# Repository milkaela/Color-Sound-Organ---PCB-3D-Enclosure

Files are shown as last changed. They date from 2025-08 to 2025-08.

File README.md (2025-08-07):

# Color Sound Organ: PCB-3D-Enclosure
This project contains a complete design for a **sound-reactive light organ** with 3 channels (bass, mid, treble), using a PCB designed in KiCad and a custom 3D-printed case modeled in FreeCAD.
It is intended as a simple analog project for beginners or hobbyists who want to create visual effects based on audio input.

## 📦 Files Included

| File | Description |
|---|---|
| `3leduri.kicad_pcb` | PCB layout for the sound organ |
| `3leduri.kicad_sch` | Schematic diagram (circuit design) |
| `3leduri.kicad_pro` | KiCad project file |
| `3leduri.kicad_prl` | Layout view settings |
| `3leduri.xml` | Netlist and BOM data export |
| `3leduri_bom_.csv`  | Bill of materials (CSV format) |
| `3leduri_bom_.xlsx` | Bill of materials (Excel format) |
| `fp-info-cache` | Footprint cache used by KiCad |
| `cutie2.1.FCStd` | 3D model of the custom case (FreeCAD format) |
---

## 🧠 Functional Description

The circuit detects three different frequency bands from an audio signal (low, mid, and high), and lights up a dedicated LED for each band accordingly.

- **Low frequencies (bass)** → LED 1
- **Mid frequencies** → LED 2
- **High frequencies (treble)** → LED 3

The PCB is designed to fit perfectly into the custom enclosure, with holes for LEDs and power input.

---

## 🛠 Tools and Technologies

- **KiCad** – for PCB design
- **FreeCAD** – for designing the case
- **3D Printer** – to fabricate the enclosure
- (Optional) **Audio signal source** – via jack, aux, or microphone

---

## 🖨️ 3D Printing Information

- Format: `.FCStd` (native FreeCAD file)
- Recommended slicer: Cura, PrusaSlicer, etc.
- Material: PLA or PETG
- Print time: ~2 hours
- No supports required

---

## ⚡ Usage & Testing

1. Assemble the circuit and solder components on the PCB
2. Insert the board into the 3D-printed case
3. Connect audio input (e.g. from your phone or laptop)
4. Play music — the 3 LEDs will respond to the audio spectrum

---

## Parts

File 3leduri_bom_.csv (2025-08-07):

Component | Description | Part | References | Value | Footprint | Quantity Per PCB | Datasheet | mfr.part.no | sup.ref | Sim.Pins
1 | Unpolarized capacitor | C | C9 | 4.7n | C_1206_3216Metric_Pad1.33x1.80mm_HandSolder | 1 | ~ | GRM31CR72E473KW03L | https://ro.mouser.com/ProductDetail/Murata-Electronics/GRM31CR72E473KW03L?qs=NdShG4hwR%2FfxjPAa9M%2FghA%3D%3D
2 | Unpolarized capacitor | C | C6 C7 | 22n | C_1206_3216Metric_Pad1.33x1.80mm_HandSolder | 2 | ~ | GRM31BR72E223KW01L | http://ro.mouser.com/ProductDetail/Murata-Electronics/GRM31BR72E223KW01L?qs=ra6ln1utXjhhO7tH%2Fqm%252BxQ%3D%3D
3 | Unpolarized capacitor | C | C3 | 0.22u | C_1206_3216Metric_Pad1.33x1.80mm_HandSolder | 1 | ~ | GRM31C5C1H224JE02L | https://ro.mouser.com/ProductDetail/Murata-Electronics/GRM31C5C1H224JE02L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
4 | Unpolarized capacitor | C | C4 | 1u | C_1206_3216Metric_Pad1.33x1.80mm_HandSolder | 1 | ~ | GCM31CR71H105KA55L | https://ro.mouser.com/ProductDetail/Murata-Electronics/GCM31CR71H105KA55L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
5 | Unpolarized capacitor | C | C5 C8 C10 | 4.7u | C_1206_3216Metric_Pad1.33x1.80mm_HandSolder | 3 | ~ | GCM31CC71H475MA03K | https://ro.mouser.com/ProductDetail/Murata-Electronics/GCM31CC71H475MA03K?qs=QzBtWTOodeVm6tBb%2FlTxEw%3D%3D
6 | Unpolarized capacitor | C | C2 | 10u | C_1206_3216Metric_Pad1.33x1.80mm_HandSolder | 1 | ~ | GRM31MR61A106KE19L | https://ro.mouser.com/ProductDetail/Murata-Electronics/GRM31MR61A106KE19L?qs=uLxxDnpYPrNhLv76oVsT4Q%3D%3D
7 | Unpolarized capacitor | C | C1 | 47u | C_1206_3216Metric_Pad1.33x1.80mm_HandSolder | 1 | ~ | GCJ31CD70G476ME01L | https://ro.mouser.com/ProductDetail/Murata-Electronics/GCJ31CD70G476ME01L
8 | Light emitting diode | LED | D1 D2 D3 D4 D5 D6 D7 D8 D9 D10 D11 D12 D13 D14 D15 D16 D17 D18 | LED | LED_D5.0mm | 18 | ~ | MTE1201C1 | https://ro.mouser.com/ProductDetail/Marktech-Optoelectronics/MTE1201C1 | 1=K 2=A
9 | Generic screw terminal, single row, 01x02, script generated (kicad-library-utils/schlib/autogen/connector/) | Screw_Terminal_01x02 | J1 J3 | Screw_Terminal_01x02 | TerminalBlock_Phoenix_MKDS-1,5-2_1x02_P5.00mm_Horizontal | 2 | ~ | 1732386 | https://ro.mouser.com/ProductDetail/Phoenix-Contact/1732386?qs=q88POAGIlTFn%2F3dpEE3JiQ%3D%3D
10 | 0.5A Ic, 300V Vce, NPN High Voltage Transistor, TO-92 | MPSA42 | Q1 Q2 Q3 Q4 Q5 Q6 Q7 Q8 | MPSA42 | TO-92_Inline | 8 | http://www.onsemi.com/pub_link/Collateral/MPSA42-D.PDF | MPSA42 | https://ro.mouser.com/ProductDetail/onsemi-Fairchild/MPSA42?qs=UMEuL5FsraDu%2F9ZWGlN1JQ%3D%3D
11 | Resistor | R | R5 | 1.2m | R_1206_3216Metric_Pad1.30x1.75mm_HandSolder | 1 | ~ | AC1206JR-071M2L | https://ro.mouser.com/ProductDetail/YAGEO/SR1206JR-1347RL?qs=xt%2FK%252BZwdrcX9lgw8VMC4Xg%3D%3D
12 | Resistor | R | R4 R17 R20 | 47r | R_1206_3216Metric_Pad1.30x1.75mm_HandSolder | 3 | ~ | SR1206JR-1347RL | https://ro.mouser.com/ProductDetail/TE-Connectivity-Neohm/EP4WSS47RJ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
13 | Resistor | R | R10 R15 R16 R16b1 R21 R21b1 | 150r | R_1206_3216Metric_Pad1.30x1.75mm_HandSolder | 6 | ~ | SR1206JR-7W150RL | https://ro.mouser.com/ProductDetail/YAGEO/SR1206JR-7W150RL?qs=1X5yxNMcnLxagzLVGX4DGA%3D%3D
14 | Resistor | R | R11 R11b1 | 270r | R_1206_3216Metric_Pad1.30x1.75mm_HandSolder | 2 | ~ | RCA1206270RJNEA | https://ro.mouser.com/ProductDetail/Vishay/RCA1206270RJNEA?qs=VVKQmw408U%2FD9LNLQdRT1g%3D%3D
15 | Resistor | R | R6 | 470r | R_1206_3216Metric_Pad1.30x1.75mm_HandSolder | 1 | ~ | SR1206KR-7W470RL | https://ro.mouser.com/ProductDetail/YAGEO/SR1206KR-7W470RL?qs=ABvmyp11Kkjj9l8C%2F3PCeg%3D%3D
16 | Resistor | R | R1 R2 | 1k | R_1206_3216Metric_Pad1.30x1.75mm_HandSolder | 2 | ~ | RV1206JR-071KL | https://ro.mouser.com/ProductDetail/YAGEO/RV1206JR-071KL?qs=HEu%2FF%2FCqxzLBGGLzy5MRbA%3D%3D
17 | Resistor | R | R7 R12 | 4.7k | R_1206_3216Metric_Pad1.30x1.75mm_HandSolder | 2 | ~ | AR1206JR-074K7L | https://ro.mouser.com/ProductDetail/YAGEO/AR1206JR-074K7L?qs=r5DSvlrkXmLp85SEw6xssw%3D%3D
18 | Resistor | R | R3 R9 R14 R19 | 10k | R_1206_3216Metric_Pad1.30x1.75mm_HandSolder | 4 | ~ | ERJ-U08J103V | https://ro.mouser.com/ProductDetail/Panasonic/ERJ-U08J103V?qs=pdFhdcvjjghFvwXjR90D9A%3D%3D
19 | Resistor | R | R8 R13 R18 | 270k | R_1206_3216Metric_Pad1.30x1.75mm_HandSolder | 3 | ~ | AF1206JR-07270KL | https://ro.mouser.com/ProductDetail/YAGEO/AF1206JR-07270KL?qs=1mbolxNpo8f656dSDva1DA%3D%3D
20 | Potentiometer | R_Potentiometer | RV1 | R_Potentiometer | Potentiometer_Bourns_3386P_Vertical | 1 | ~ | 3386P-1-564LF | https://ro.mouser.com/ProductDetail/Bourns/3386P-1-564LF
Component Groups: | 20
Component Count: | 63
Fitted Components: | 63
Number of PCBs: | 1
Total components: | 63
Schematic Version:
Schematic Date:
PCB Variant: | default
BoM Date: | 2025-07-24T14:40:16+0300
Schematic Source: | 3leduri.kicad_sch
KiCad Version: | Eeschema 9.0.3

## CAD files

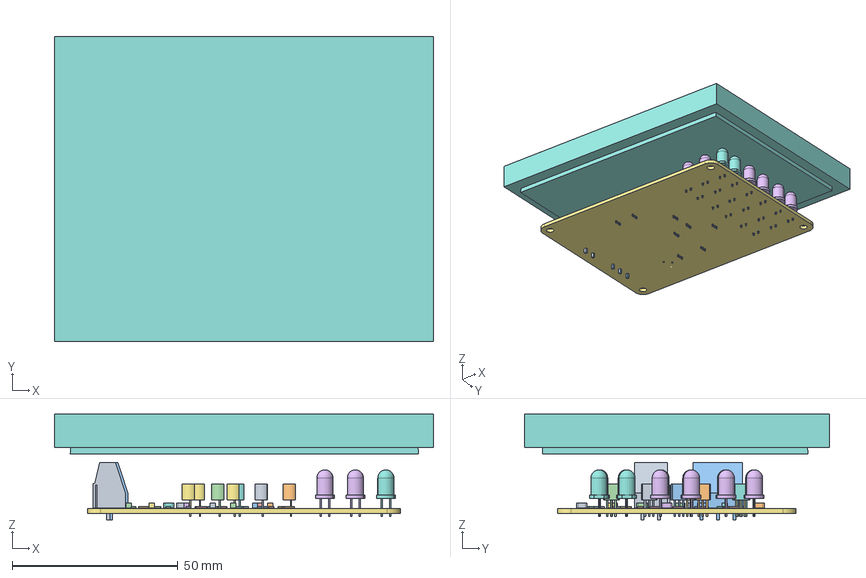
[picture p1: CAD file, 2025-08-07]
cutie2.1.FCStd
114.5 x 92.0 x 31.9 mm
R_1206_3216Metric
R_1206_3216Metric001
LED_D5.0mm
TO-92_Inline
R_1206_3216Metric002
LED_D5.0mm001
R_1206_3216Metric003
LED_D5.0mm002
LED_D5.0mm003
R_1206_3216Metric004
R_1206_3216Metric005
R_1206_3216Metric006
R_1206_3216Metric007
LED_D5.0mm004
C_1206_3216Metric
LED_D5.0mm005
TO-92_Inline001
C_1206_3216Metric001
R_1206_3216Metric008
R_1206_3216Metric009
C_1206_3216Metric002
LED_D5.0mm006
R_1206_3216Metric010
LED_D5.0mm007
C_1206_3216Metric003
R_1206_3216Metric011
LED_D5.0mm008
LED_D5.0mm009
R_1206_3216Metric012
LED_D5.0mm010
TO-92_Inline002
R_1206_3216Metric013
R_1206_3216Metric014
LED_D5.0mm011
TO-92_Inline003
C_1206_3216Metric004
R_1206_3216Metric015
R_1206_3216Metric016
LED_D5.0mm012
TO-92_Inline004
R_1206_3216Metric017
TO-92_Inline005
C_1206_3216Metric005
R_1206_3216Metric018
R_1206_3216Metric019
LED_D5.0mm013
TO-92_Inline006
C_1206_3216Metric006
TerminalBlock_Phoenix_MKDS-1,5-2_1x02_P5.00mm_Horizontal
R_1206_3216Metric020
TerminalBlock_Phoenix_MKDS-1,5-3_1x03_P5.00mm_Horizontal
R_1206_3216Metric021
LED_D5.0mm014
C_1206_3216Metric007
TO-92_Inline007
LED_D5.0mm015
C_1206_3216Metric008
LED_D5.0mm016
R_1206_3216Metric022
C_1206_3216Metric009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

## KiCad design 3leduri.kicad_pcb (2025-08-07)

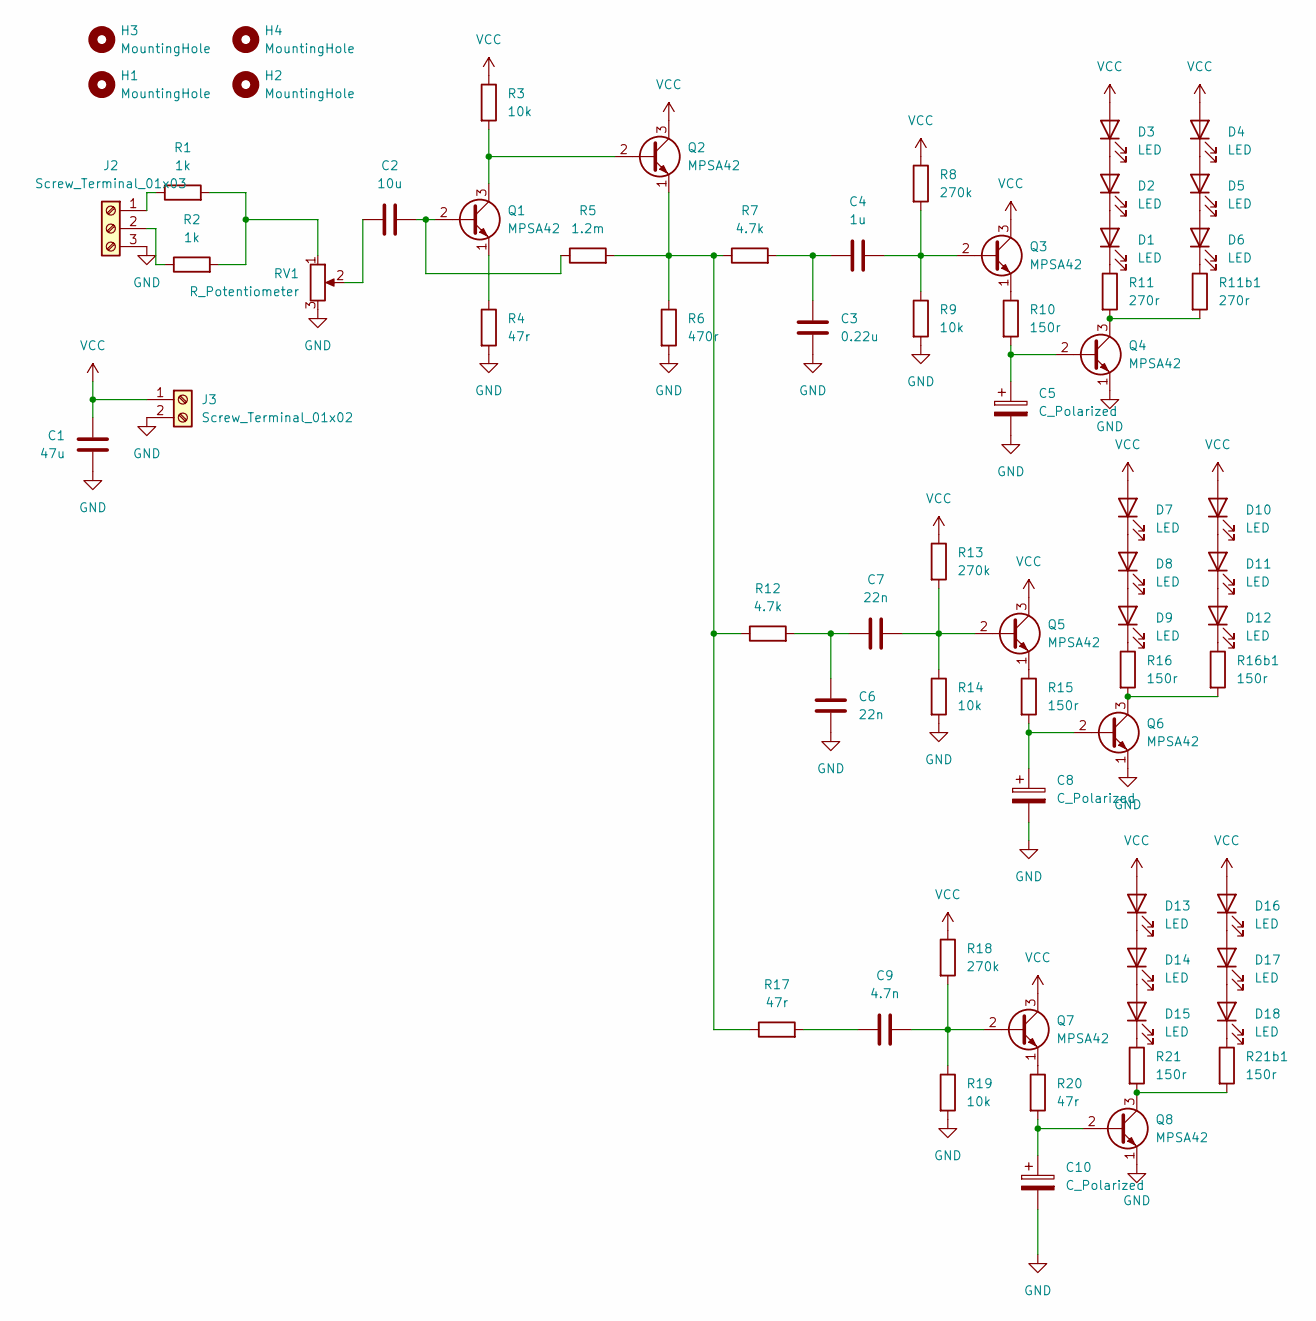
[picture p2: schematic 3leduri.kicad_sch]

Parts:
C1: 47u; C_1206_3216Metric_Pad1.33x1.80mm_HandSolder; mfr.part.no GCJ31CD70G476ME01L
C2: 10u; C_1206_3216Metric_Pad1.33x1.80mm_HandSolder; mfr.part.no GRM31MR61A106KE19L
C3: 0.22u; C_1206_3216Metric_Pad1.33x1.80mm_HandSolder; mfr.part.no GRM31C5C1H224JE02L
C4: 1u; C_1206_3216Metric_Pad1.33x1.80mm_HandSolder; mfr.part.no GCM31CR71H105KA55L
C5, C8, C10: C_Polarized; C_1206_3216Metric_Pad1.33x1.80mm_HandSolder
C6, C7: 22n; C_1206_3216Metric_Pad1.33x1.80mm_HandSolder; mfr.part.no GRM31BR72E223KW01L
C9: 4.7n; C_1206_3216Metric_Pad1.33x1.80mm_HandSolder; mfr.part.no GRM31CR72E473KW03L
D1, D2, D3, D4, D5, D6, D7, D8, D9, D10, D11, D12, D13, D14, D15, D16, D17, D18: LED; LED_D5.0mm; mfr.part.no MTE1201C1
H1, H2, H3, H4: MountingHole; MountingHole_3.2mm_M3
J2: Screw_Terminal_01x03; TerminalBlock_Phoenix_MKDS-1,5-3_1x03_P5.00mm_Horizontal
J3: Screw_Terminal_01x02; TerminalBlock_Phoenix_MKDS-1,5-2_1x02_P5.00mm_Horizontal; mfr.part.no 1732386
Q1, Q2, Q3, Q4, Q5, Q6, Q7, Q8: MPSA42; TO-92_Inline; mfr.part.no MPSA42
R1, R2: 1k; R_1206_3216Metric_Pad1.30x1.75mm_HandSolder; mfr.part.no RV1206JR-071KL
R3, R9, R14, R19: 10k; R_1206_3216Metric_Pad1.30x1.75mm_HandSolder; mfr.part.no ERJ-U08J103V
R4, R17, R20: 47r; R_1206_3216Metric_Pad1.30x1.75mm_HandSolder; mfr.part.no SR1206JR-1347RL
R5: 1.2m; R_1206_3216Metric_Pad1.30x1.75mm_HandSolder; mfr.part.no AC1206JR-071M2L
R6: 470r; R_1206_3216Metric_Pad1.30x1.75mm_HandSolder; mfr.part.no SR1206KR-7W470RL
R7, R12: 4.7k; R_1206_3216Metric_Pad1.30x1.75mm_HandSolder; mfr.part.no AR1206JR-074K7L
R8, R13, R18: 270k; R_1206_3216Metric_Pad1.30x1.75mm_HandSolder; mfr.part.no AF1206JR-07270KL
R10, R15, R16, R16b1, R21, R21b1: 150r; R_1206_3216Metric_Pad1.30x1.75mm_HandSolder; mfr.part.no SR1206JR-7W150RL
R11, R11b1: 270r; R_1206_3216Metric_Pad1.30x1.75mm_HandSolder; mfr.part.no RCA1206270RJNEA
RV1: R_Potentiometer; Potentiometer_Bourns_3386P_Vertical; mfr.part.no 3386P-1-564LF

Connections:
GND: C1.2, C3.2, C5.2, C6.2, C8.2, C10.2, J2.3, J3.2, Q4.1 (E), Q6.1 (E), Q8.1 (E), R4.2, R6.2, R9.2, R14.2, R19.2, RV1.3
unnamed: C2.1, RV1.2
unnamed: C3.1, C4.1, R7.2
unnamed: C6.1, C7.1, R12.2
unnamed: C9.1, R17.2
unnamed: D1.2 (A), D2.1 (K)
unnamed: D1.1 (K), R11.1
unnamed: D2.2 (A), D3.1 (K)
unnamed: D4.1 (K), D5.2 (A)
unnamed: D5.1 (K), D6.2 (A)
unnamed: D6.1 (K), R11b1.1
unnamed: D7.1 (K), D8.2 (A)
unnamed: D8.1 (K), D9.2 (A)
unnamed: D9.1 (K), R16.1
unnamed: D10.1 (K), D11.2 (A)
unnamed: D11.1 (K), D12.2 (A)
unnamed: D12.1 (K), R16b1.1
unnamed: D13.1 (K), D14.2 (A)
unnamed: D14.1 (K), D15.2 (A)
unnamed: D15.1 (K), R21.1
unnamed: D16.1 (K), D17.2 (A)
unnamed: D17.1 (K), D18.2 (A)
unnamed: D18.1 (K), R21b1.1
unnamed: J2.1, R1.1
unnamed: J2.2, R2.1
unnamed: C2.2, Q1.2 (B), R5.1
unnamed: Q1.3 (C), Q2.2 (B), R3.2
unnamed: Q1.1 (E), R4.1
unnamed: Q2.1 (E), R5.2, R6.1, R7.1, R12.1, R17.1
unnamed: C4.2, Q3.2 (B), R8.2, R9.1
unnamed: Q3.1 (E), R10.1
unnamed: C5.1, Q4.2 (B), R10.2
unnamed: Q4.3 (C), R11.2, R11b1.2
unnamed: C7.2, Q5.2 (B), R13.2, R14.1
unnamed: Q5.1 (E), R15.1
unnamed: C8.1, Q6.2 (B), R15.2
unnamed: Q6.3 (C), R16.2, R16b1.2
unnamed: C9.2, Q7.2 (B), R18.2, R19.1
unnamed: Q7.1 (E), R20.1
unnamed: C10.1, Q8.2 (B), R20.2
unnamed: Q8.3 (C), R21.2, R21b1.2
unnamed: R1.2, R2.2, RV1.1
VCC: C1.1, D3.2 (A), D4.2 (A), D7.2 (A), D10.2 (A), D13.2 (A), D16.2 (A), J3.1, Q2.3 (C), Q3.3 (C), Q5.3 (C), Q7.3 (C), R3.1, R8.1, R13.1, R18.1

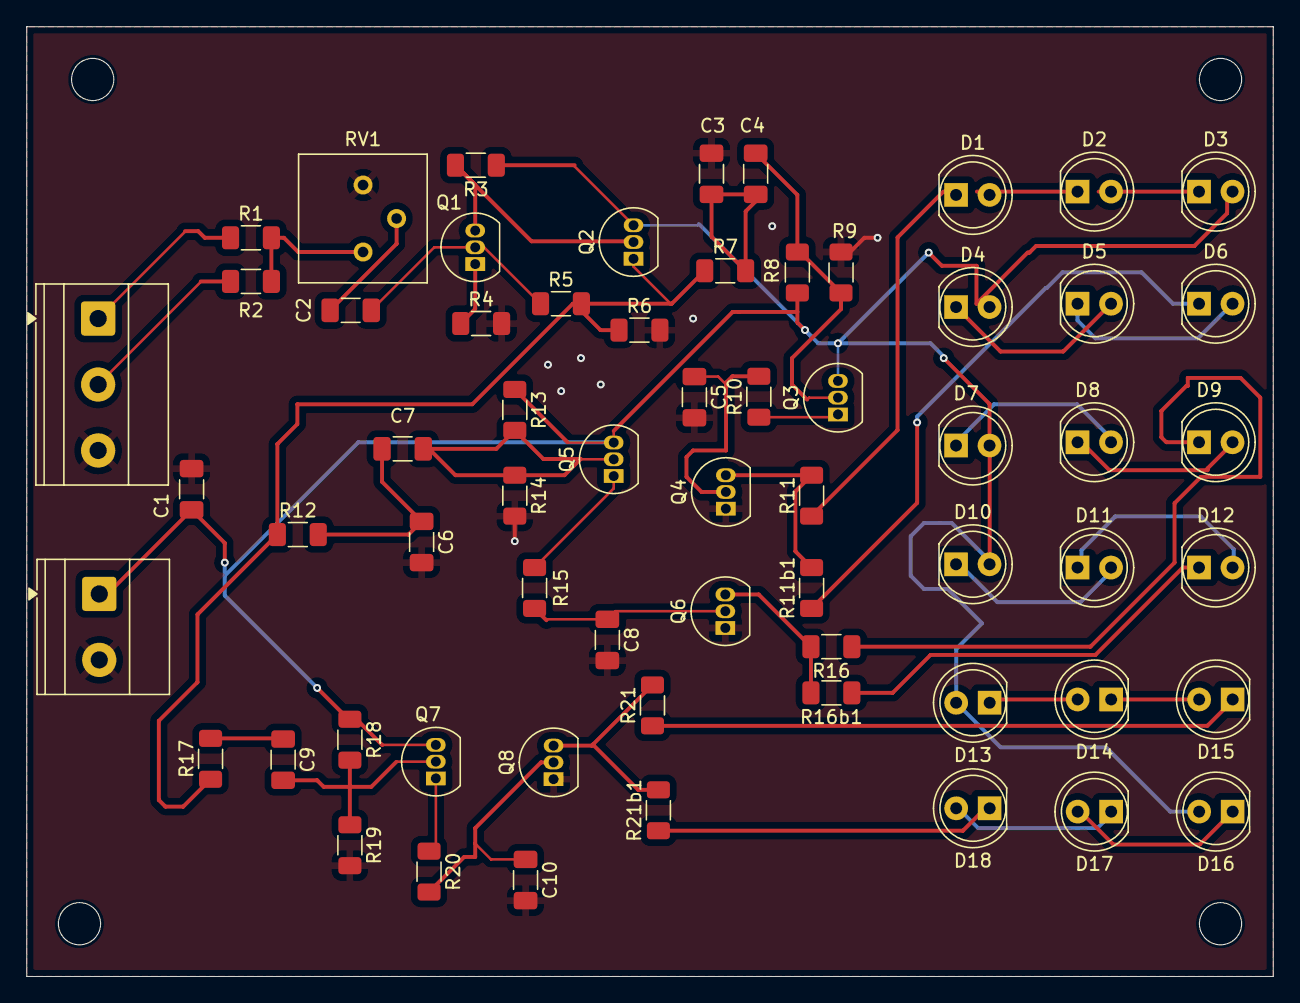
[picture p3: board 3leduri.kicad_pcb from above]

Board: 2 copper layers, 94.5 x 72.0 mm, 67 parts (0 on the bottom side), 43 nets.

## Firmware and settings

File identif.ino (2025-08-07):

// example.ino
// This is a placeholder sketch to classify the repository as an Arduino-related hardware project.

// Project Summary:
// This repository contains a sound-reactive 3-channel light organ,
// designed entirely using KiCad (PCB) and FreeCAD (3D enclosure).
// It is an analog circuit that lights up 3 LEDs based on bass, mid, and treble frequencies.

// Technologies Involved:
// - KiCad: for PCB layout and schematic
// - FreeCAD: for 3D printable enclosure
// - Passive and analog active filters: frequency band separation
// - Hardware assembly and real-world testing

// This project demonstrates hardware design skills,
// analog electronics knowledge, and full project integration (from schematic to physical build).

void setup() {
  // Nothing to run — this file is here for classification and documentation only.
}

void loop() {
  // No code needed for analog project.
}
